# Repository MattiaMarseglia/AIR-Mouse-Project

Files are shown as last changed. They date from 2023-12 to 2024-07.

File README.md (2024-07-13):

# Air Mouse System Fingers Based (STM32CubeIDE)
<div align='center'>
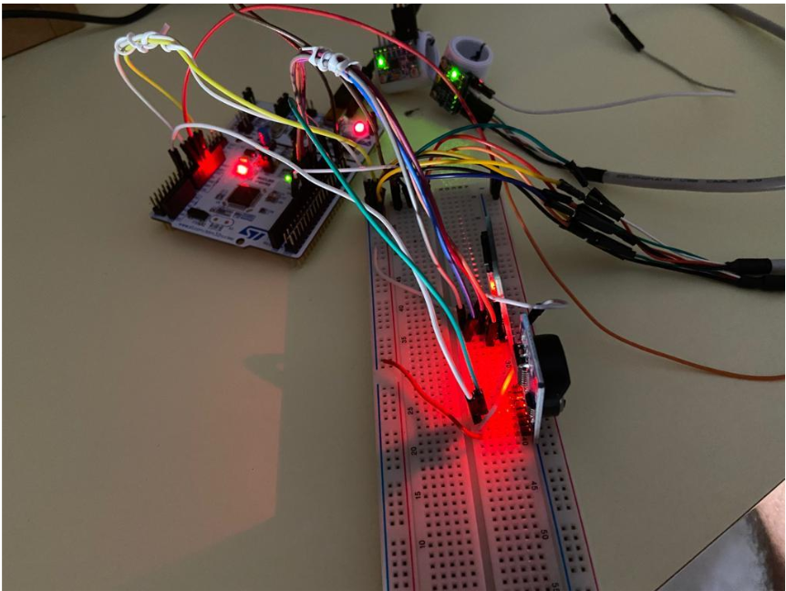
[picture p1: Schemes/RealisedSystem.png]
  
</div>

## Overview
The **Air Mouse System Fingers Based** project involves the creation of a gesture-controlled mouse using a combination of accelerometers, gyroscopes, a real-time clock (RTC), and an SD card module. The goal is to allow users to control their computer's mouse cursor by moving their fingers in the air, creating patterns and gestures for various actions, like movement, click, double-click etc.

## Developed System 
For the realisation of the Air Mouse, it was necessary to: 
- create a system capable of interpreting the basic commands of a common mouse, like **single click**, **double click**, **zoom in**, **zoom out**, **ALT-TAB**, with a specific fingers movement, acquiring data from accelerometers;
- create a system capable of **recording each event** (e.g. movement) by acquiring the timestamp from the RTC and writing it to the SD card witha representation such as: from:(x,y,z); to:(x,y ,z); accel: (x,y,z); gyro: (x,y,z) etc.;
- define different tasks for different activities(log, sensors' input, etc.), employing FreeRTOS, eventually with time constraints;
- design a suitable communication protocol from the STM32-Air mouse to the PC;
- define a calibration procedure.
- create a system that is correct, verifiable, modular and easily maintainable but also ready and fluid in responding to finger movements.

### Hardware
#### Hardware Components
- STM32F401RET6 board from the Nucleo series;
- 2 Modulo GY-521, build to manage MPU-6050, which combines an 3-axis accelerometer, a 3-axis gyroscope, a temperature sensor, an internal clock oscillation and a digital motion processor (DMP);
- Real-Time Clock (RTC) DS3231;
- Micro SD card adapter module;
#### Hardware Architecture
As can be seen in the high-level hardware architecture, it was necessary to interface the board and thus the processor with external peripherals. The board in turn is connected to the PC to which, as soon as the code has been loaded, it will transmit the data obtained, which will be reflected in mouse movements.  This data will be obtained by processing the values measured by the accelerometers along the three axes. The other two sensors, namely the RTC and the SD are functional to the development of a log file, saved on an SD card contained within the SD module. Specifically, the Real Time Clock is required to obtain a timestamp, so that all recorded movements and their associated values can be documented on the file, placing them temporally.
<div align='center'>
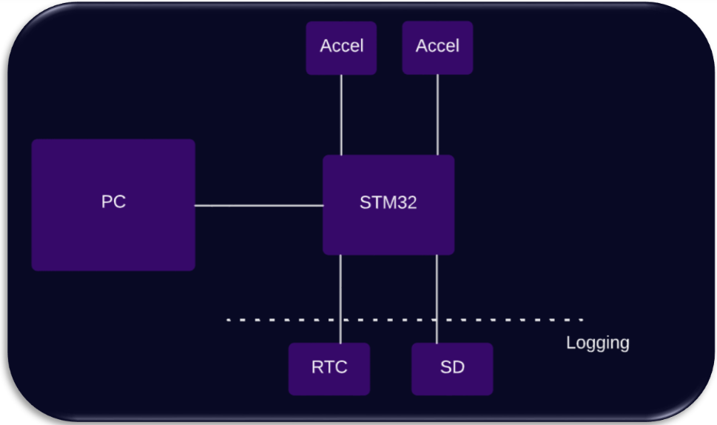
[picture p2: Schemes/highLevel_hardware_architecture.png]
High Level Hardware Architecture
  
</div>

As can be seen in the low-level hardare architecture, it was necessary to make use of a breadbord. 
<div align='center'>
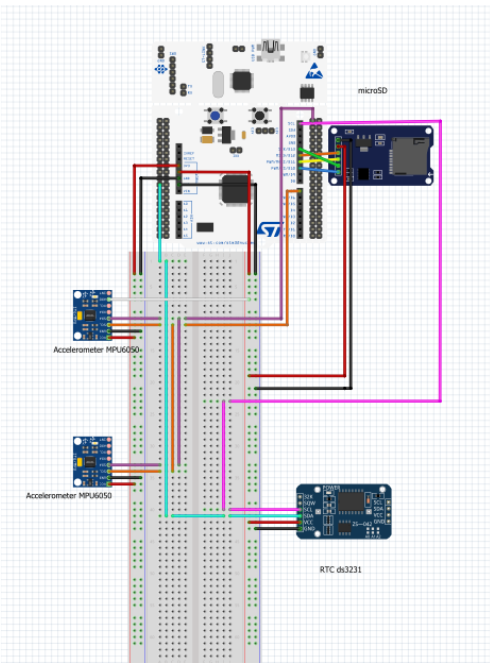
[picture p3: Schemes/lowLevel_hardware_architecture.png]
Low Level Hardware Architecture
  
</div>

For more details on the description of the connections made, please refer to the [report](ProgettoFinale_SE.pdf).

### Communication interface
Both the Real Time Clock and the two Accelerometers require I2C channels for communication with the board. So it was necessary to realise a protocol scheme that allows data acquisition from all sensors without creating overlaps. To this end, the board's availability of more than one I2C channel was exploited, as well as the possibility associated with the accelerometers alone, to be able to set up a register shift through which the
master can communicate with them. So that there was no overlap between the values communicated by the two different accelerometers. The microSD reader, on the other hand, uses an SPI connection. The communication with the PC is established through USART/UART, using a USB connection.
For more details about these comunication protocols, please refer to the [report](ProgettoFinale_SE.pdf).

### Software
#### Software Components
- STM32CubeIDE, an all-in-one multi-OS development tool, part of the STM32Cube software ecosystem;
- FreeRTOS, a space-saving, portable and open source real-time operating system (RTOS) for microcontrollers.
- PyAutoGUI, a Python GUI automation module cross-platform for humans, used to control at the code level the mouse and keyboard, and very useful to translate accelerometer values into mouse movements.
- PySerial, a module encapsulating the access for the serial port, that is useful to realise communication with the STM32 board so that motion commands can be acquired through the UART communication protocol.

#### Software Architecture
The software architecture was realised by identifying three tasks of freeRTOS with the same priority and different functionalities. The implemented tasks were identified from the
main functionalities that were to be offered by the system. So, a first *LectureTask* was implemented for the acquisition of data from accelerometers, which has a stack size of 128 words and whose priority is RealTime. The second task *AnalysisTask*, with a stack size of 128 words and a RealTime priority, deputed to recognize, depending on the values obtained from the accelerometers, which movement has to be made and send that analysis to the UART so that it can then communicate with the python modules to execute the user's commands. The third *LogTask* task, on the other hand, is responsible for writing the log file to the SD card and has a stack larger stack size of 2048 words and a RealTime priority. So, the read task is a periodic task. The activity of the other two tasks, on the other hand, depends on the presence of values to be parsed within the queues. Specifically, the queues created
were two: the first *LtoAqueue* serves as the
connection between the read task and the analysis task, the second *AtoLogqueue* serves as the connection between the analysis task and the log task. 

The control software was realised in C, for more details on the implemented modules, please refer to the [report](ProgettoFinale_SE.pdf).

## Repository Structure
- `ConfigTrio_RTC_1A2ASisEmbFinalProject/`: contains all the code developed for the system;
- `ProvaMouse`: contains a python script to test the system;
- `FinalProjectSistEmbBreadboard.fzz` and `SchemaConnessioni.fzz`: are the projects of the connection schemes;
- `ProgettoFinale_SE.pdf`: is the final report containing descriptive diagrams of the realised architecture, the motivations underlying certain design choices, details of the developed modules, hardare and software components descriptions and images depicting how to use the system;

## DEMO 
[Here](https://youtu.be/58L7y2n-bBM) it is possible to see a demo video of the developed system and all the implemented features.

## Feedback
For any feedback, questions or inquiries, please contact the project maintainers listed in the Contributors section.

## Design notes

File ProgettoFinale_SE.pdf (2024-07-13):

# Air Mouse – Fingers

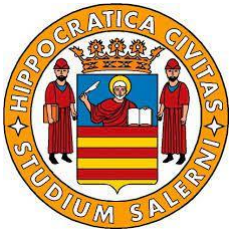
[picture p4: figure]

# AIR MOUSE – FINGERS

# Sistemi Embedded

# Final Project

Based on STM32F401RET6

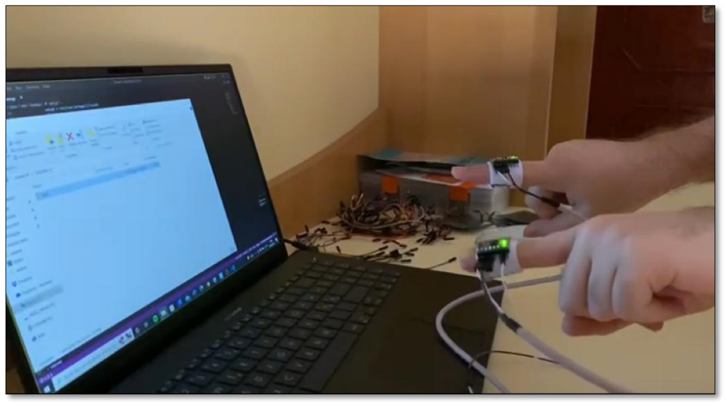
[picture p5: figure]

GRUPPO | | C.d.L. Ingegneria Informatica Magistrale
Vito Turi | 0622701795 | A.A. 2021/2022
Ferdinando Sica | 0622701794
Camilla Spingola | 0622701698
Mattia Marseglia | 0622701697

## Sommario

PySerial 30

## 1 Introduzione

## 1.1 Scopo del documento

Questo documento si pone l’obiettivo di descrivere lo sviluppo del progetto finale del corso di Sistemi Embedded, che ha

riguardato la realizzazione di un Air Mouse, utilizzabile tramite le dita di una mano.

Il presente documento viene allegato al progetto finale come documentazione ufficiale, al fine di offrire una descrizione

completa delle specifiche funzionali del sistema, nonché della componentistica hardware utilizzata e dell’architettura

software implementata.

## 1.2 Scopo del progetto

Il progetto finale del corso di Sistemi Embedded ha riguardato la realizzazione di un dispositivo Air Mouse controllabile

con le mani, in grado di interpretare la maggior parte dei comandi eseguibili attraverso un comune mouse (movimento,

click, double click etc.…), che analizzeremo successivamente.

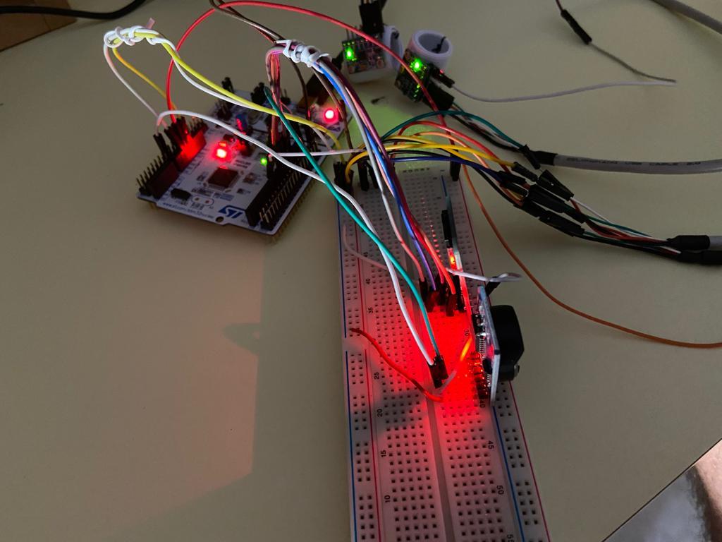
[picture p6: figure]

## 2 Hardware utilizzato

## 2.1 Descrizione della board

Per la progettazione e la realizzazione dell’Air Mouse, è stata utilizzata la board STM32F401RET6 della serie Nucleo. I

dispositivi STM32F401xD/xE sono basati sul core RISC a 32 bit ARMCortex-M4 ad alte prestazioni che opera a una

frequenza fino a 84 MHz. Il suo core Cortex-M4 è dotato di un'unità a virgola mobile (FPU) a precisione singola che

supporta tutte le istruzioni di processing dei dati e tutti i tipi di dato a singola precisione ARM. Implementa inoltre un set

completo di istruzioni DSP e un'unità di protezione della memoria (MPU) che migliora la sicurezza delle applicazioni.

STM32F401xD/xE incorpora memorie embedded ad alta velocità (512 Kbyte di memoria Flash, 96 Kbyte di SRAM) e una

vasta gamma di I/O e periferiche avanzate collegate a due bus APB, a due bus AHB e a una matrice bus multi-AHB a 32

bit.

Tutti i dispositivi offrono un ADC a 12 bit, un RTC a bassa potenza, 6 timer a 16 bit per uso generico, tra cui un timer

PWM per il controllo del motore, due timer a 32 bit per uso generale. Sono inoltre dotati di interfacce di comunicazione

standard e avanzate.

### Caratteristiche

- Core: CPU Arm32-bit Cortex-M4 con FPU, acceleratore adattivo in tempo reale (ART Accelerator™) che consente

l'esecuzione dello stato di attesa 0 dalla memoria Flash, frequenza fino a 84 MHz, unità di protezione della memoria, 105

DMIPS / 1,25 DMIPS / MHz (Dhrystone 2.1) e istruzioni DSP

- Memoria
- fino a 512 Kbyte di memoria Flash
- fino a 96 Kbyte di SRAM
- Gestione del clock, del reset e dell’alimentazione
- Alimentazione dell'applicazione e I/O da 1,7 V a 3,6 V
- POR, PDR, PVD e BOR
- Oscillatore a cristallo da 4 a 26 MHz
- RC interno a 16 MHz
- Oscillatore 32 kHz per RTC con calibrazione
- RC interno a 32 kHz con calibrazione
- Consumo energetico
- Funzionamento: 146 μA/MHz (periferica spenta)
- Stop (Flash in modalità Stop, fast wake-up time): 42 μA Typ @ 25C; 65 μA max @25 °C
- Stop (Flash in modalità Deep power down, fast wake-up time): fino a 10 μA @ 25 °C; 30 μA max @25 °C
- Standby: 2,4 μA @ 25 °C / 1,7 V senza RTC; 12 μA @85 °C @1.7 V
- alimentazione per RTC: 1 μA @25 °C

- Convertitore A/D 1×12 bit, 2.4 MSPS: fino a 16 canali
- DMA per uso generico: controller DMA a 16 flussi con FIFO e supporto burst
- Fino a 11 timer: fino a sei timer a 16 bit, due timer a 32 bit fino a 84 MHz, ciascuno con un massimo di quattro IC/OC/PWM o

un contatore di impulsi e un ingresso encoder in quadratura (incrementale), due timer watchdog (indipendenti e finestrato) e un

timer SysTick

- Modalità di debug
- Interfacce SWD (Serial Wire Debug) e JTAG
- Cortex-M4 Embedded Trace Macrocell
- Fino a 81 porte I/O con capacità di interruzione
- Fino a 78 I/O veloci fino a 42 MHz
- Tutte le porte I/O sono tolleranti a 5 V
- Fino a 12 interfacce di comunicazione
- Fino a 3 Interfacce 12C (SMBus/PMBus)
- Fino a 3 USART (2 x 10,5 Mbit/s, 1 x 5,25 Mbit/s), interfaccia ISO 7816, LIN, IrDA, controllo modem)
- Fino a 4 SPI (fino a 42Mbit/s a fCPU= 84 MHz), SPI2 e SPI3 con muxed full-duplex I2S per ottenere la precisione

della classe audio attraverso l’audio interno PLL o il clock esterno

- Interfaccia SDIO
- Connettività avanzata: USB 2.0 full speed device/ host / controller OTG con PHY su chip
- Unità di calcolo CRC
- ID univoco a 96 bit
- RTC: precisione al di sotto del secondo, calendario hardware

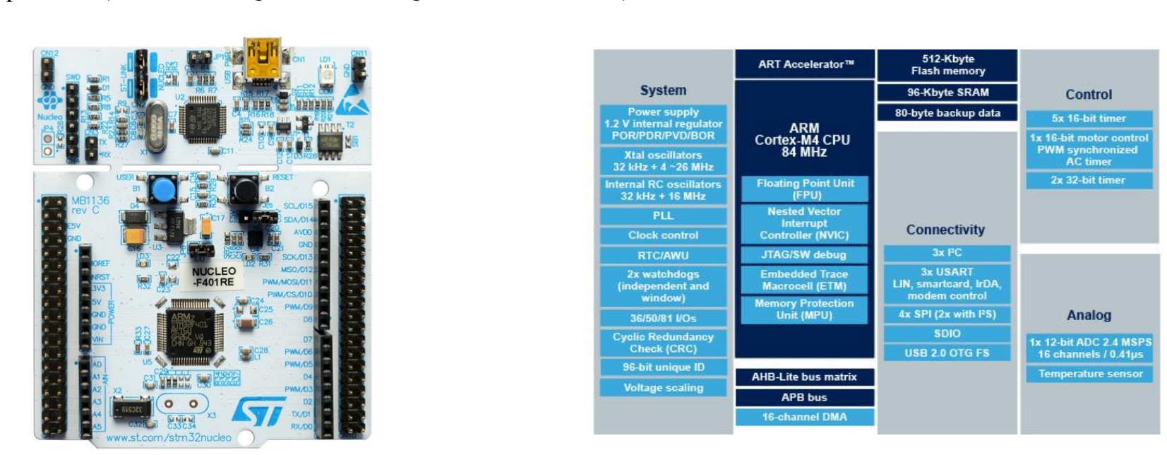
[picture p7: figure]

- Tutti i pacchetti (WLCSP49, LQFP64/100, UFQFPN48, UFBGA100) sono ECOPACK2

## 2.2 Descrizione dei sensori

### Modulo GY-521 MPU-6050

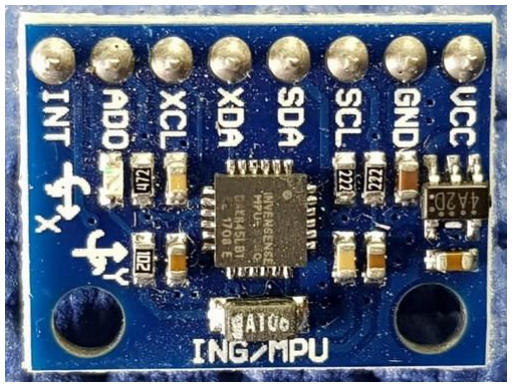
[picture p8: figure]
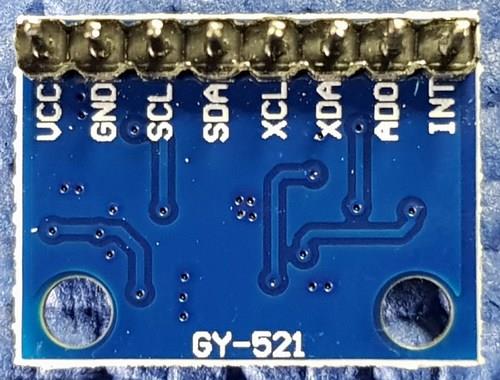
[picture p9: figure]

Il modulo GY-521 (https://win.adrirobot.it/sensori/MPU-6050/sensore_MPU-6050.htm) è costruito per gestire il sensore MPU-6050 che combina al suo interno più dispositivi, tra i quali

notiamo:

- un accelerometro a 3 assi
- un giroscopio a 3 assi
- un sensore di temperatura
- un oscillare di clock interno
- un processore di movimento digitale

Il modulo è di piccole dimensioni: 21.2 x 16.4 x 3.3 mm, è dotato in hardware di conversione analogico-digitale per

ciascun canale, e consente l’acquisizione dai canali x, y, z. L'uscita può essere interfacciata con il bus I2C.

Accelerometro a 3 assi

L'accelerometro a 3 assi interno all'MPU-6050 è in grado di rilevare l'angolo di inclinazione o l'inclinazione lungo gli assi

x, y, z utilizzando una tecnologia del sistema elettromeccanico (Micro Electro-Mechanical Systems MEMS). (https://it.wikipedia.org/wiki/MEMS)

L'accelerazione lungo gli assi è ricavata dalla massa in movimento c, rilevata con la tecnologia del sistema

elettromeccanico (MEMS). Per la digitalizzazione dei valori viene utilizzato un ADC a 16 bit. Gli intervalli di uscita a

fondo scala possibili sono: +/- 2g, +/- 4g, +/- 8g, +/- 16g.

In posizione normale, cioè quando il dispositivo è posizionato su una superficie piana, i valori sono 0 g sull'asse x, 0 g

sull'asse y e +1 sull'asse z.

Giroscopio a 3 assi

L'MPU-6050 è costituito da un giroscopio a 3 assi in grado di rilevare la velocità di rotazione lungo l'asse x, y, z con la

tecnologia del sistema micro-elettromeccanico (MEMS). Quando il sensore viene ruotato su qualsiasi asse, viene prodotta

una vibrazione, grazie all'effetto Coriolis (https://it.wikipedia.org/wiki/Forza_di_Coriolis) viene rilevata dal MEMS. L'ADC a 16 bit viene utilizzato per digitalizzare la

tensione per campionare ciascun asse. Gli intervalli di uscita a fondo scala sono: +/- 250, +/- 500, +/- 1000, +/- 2000. La

velocità angolare viene misurata lungo ciascun asse in gradi al secondo.

Oscillatore di clock interno

L'MPU ha uno schema di temporizzazione flessibile, che consente di utilizzare una varietà di sorgenti di clock interne o

esterne per i circuiti sincroni interni. Questa circuiteria sincrona include il segnale di condizionamento e gli ADC, il DMP e

i vari circuiti e registri di controllo. Un PLL su chip offre flessibilità negli input consentiti per generare il clock.

Le fonti interne consentite per generare il clock interno sono:

- Un oscillatore di rilassamento interno
- Qualunque giroscopio X, Y o Z (oscillatori MEMS con una variazione di ± 1% rispetto alla temperatura)

Digital motion processor (DMP)

Il processore di movimento digitale incorporato viene utilizzato per eseguire calcoli sui dati del sensore. I valori possono

essere letti dai registri dmp. I valori grezzi possono essere letti direttamente dall'accelerometro e dai registri del giroscopio.

Il chip MPU-6050 include anche un buffer FIFO da 1024 byte dove i dati possono essere posizionati e letti. L'MPU-6050

funge sempre da slave quando è connesso alla scheda con i pin SDA e SCL collegati al bus I2C. Ma ha anche il proprio

controller I2C ausiliario che gli consente di agire come un master su un altro dispositivo (come per esempio un

magnetometro). Il DMP integrato può essere programmato con il firmware per eseguire calcoli complessi con i valori del

sensore.

L'AD0 seleziona tra gli indirizzi I2C 0x68 e 0x69 consentendo a 2 di questi sensori di essere connessi nello stesso progetto

agli stessi pin senza creare sovrapposizione tra i dati. La maggior parte delle schede come la GY-521 ha una resistenza pull

down o pull up per mantenere il valore predefinito, nel nostro caso al valore 0x68.

Caratteristica sensore

Alimentazione a 5Vcc

Fondo scala giroscopio selezionabile tra ± 250, ± 500, ± 1000, e ± 2000°/sec

Fondo scala accelerometro selezionabile tra ± 2g, ± 4g, 8g ± e ± 16g

Interfaccia I2C

Assorbimento inferiore a 10mA durante la misura

Descrizione dei Pin

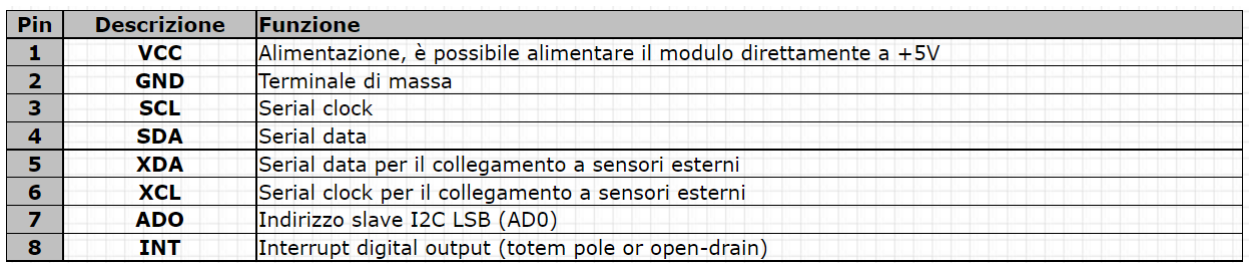
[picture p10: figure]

### Real Time Clock ds3231

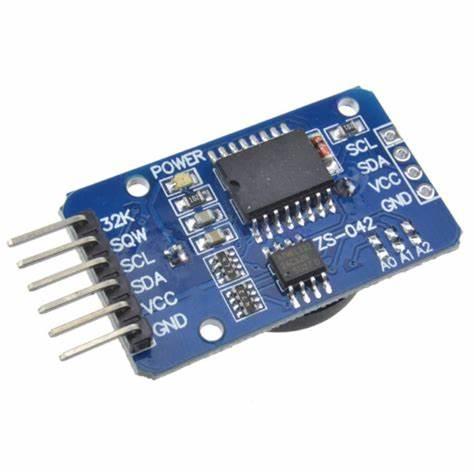
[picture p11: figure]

Il DS3231 è un Real Time Clock estremamente preciso e a basso consumo, con un TCXO (temperature compensated

crystal oscillator) integrato. Il dispositivo incorpora un ingresso batteria e mantiene un cronometraggio accurato anche

quando l'alimentazione principale al dispositivo viene interrotta. L'RTC mantiene secondi, minuti, ore, giorni, mese e anno.

La data relativa alla fine del mese viene regolata automaticamente per i mesi con meno di 31 giorni, comprese le correzioni

per l'anno bisestile. L'orologio funziona nel formato 24 ore o 12 ore con un indicatore AM/PM. Sono forniti due allarmi

programmabili e un'uscita ad onda quadra programmabile. Indirizzi e dati vengono trasferiti in serie attraverso un bus

bidirezionale I2C.

Un riferimento di tensione di precisione con compensazione della temperatura e un circuito comparatore controlla lo stato

di VCC per individuare interruzioni di corrente, per fornire un’uscita di ripristino e per passare automaticamente

all'alimentazione di riserva quando necessario.

Features

- Highly Accurate RTC Completely Manages All
- Timekeeping Functions
- Real-Time Clock Counts Seconds, Minutes, Hours,
- Date of the Month, Month, Day of the Week, and Year, with Leap-Year Compensation Valid Up to 2100
- Accuracy ±2ppm from 0°C to +40°C
- Accuracy ±3.5ppm from -40°C to +85°C
- Digital Temp Sensor Output: ±3°C Accuracy
- Register for Aging Trim
- RST Output/Pushbutton Reset Debounce Input
- Two Time-of-Day Alarms
- Programmable Square-Wave Output Signal
- Simple Serial Interface Connects to Most Microcontrollers
- Fast (400kHz) I2C Interface
- Battery-Backup Input for Continuous Timekeeping
- Low Power Operation Extends Battery-Backup Run Time
- 3.3V Operation
- Operating Temperature Ranges: Commercial (0°C to +70°C) and Industrial (-40°C to +85°C)

Operating circuit

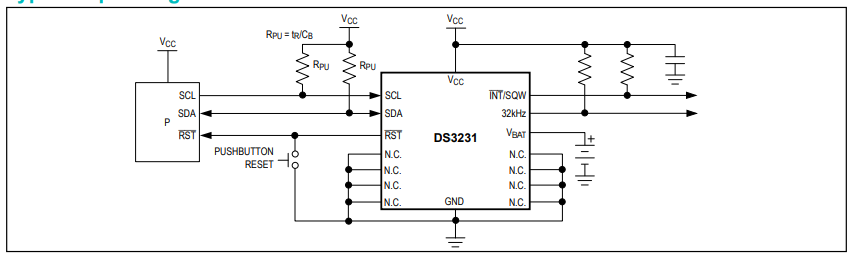
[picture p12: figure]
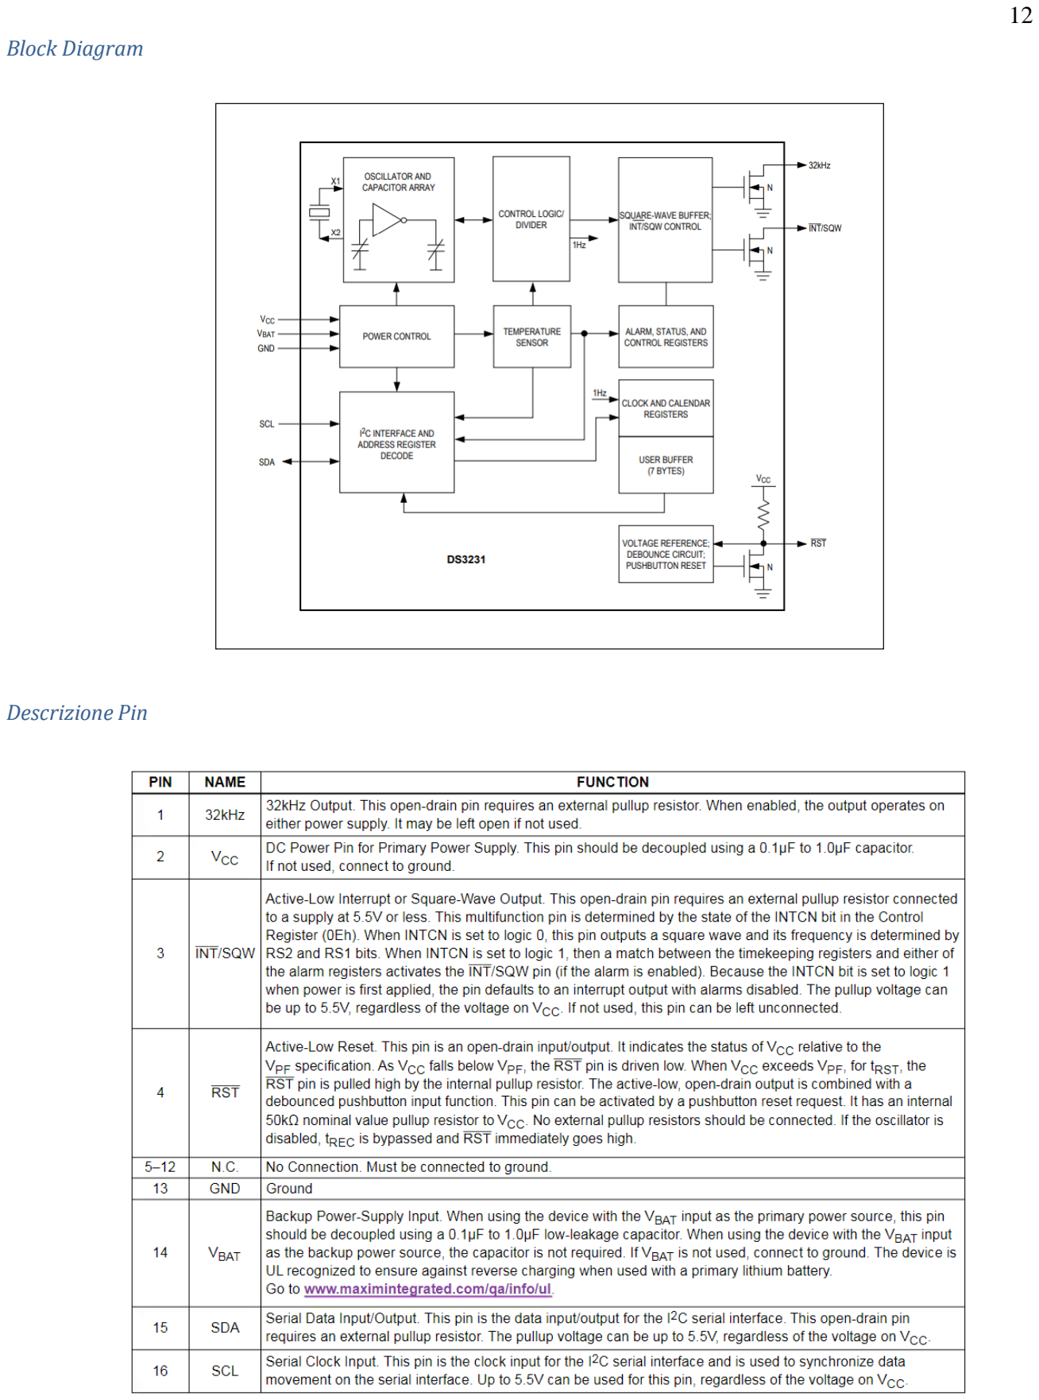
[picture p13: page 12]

Block Diagram

Descrizione Pin

### Modulo adattatore per scheda Micro SD

Le schede SD o Micro SD sono ampiamente utilizzate in varie applicazioni, come la registrazione dei dati, la

visualizzazione dei dati e molte altre. I moduli Micro SD Card Adapter rendono possibile accedere a queste schede SD con

facilità. Il modulo Micro SD Card Adapter è dotato di un'interfaccia SPI e di un regolatore di tensione da 3,3 V integrato

per fornire una corretta alimentazione alla scheda SD.

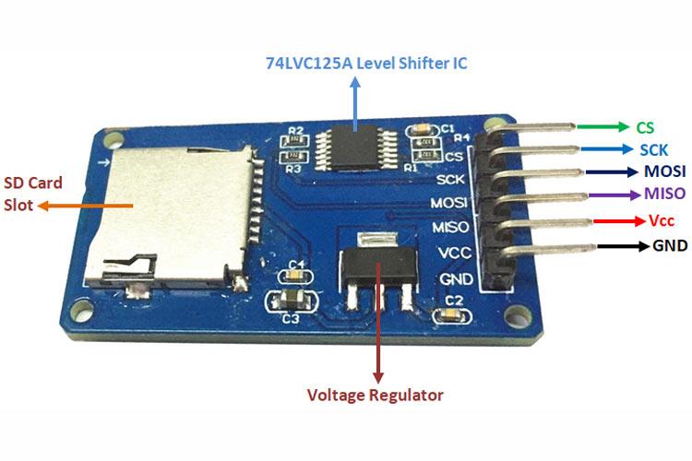
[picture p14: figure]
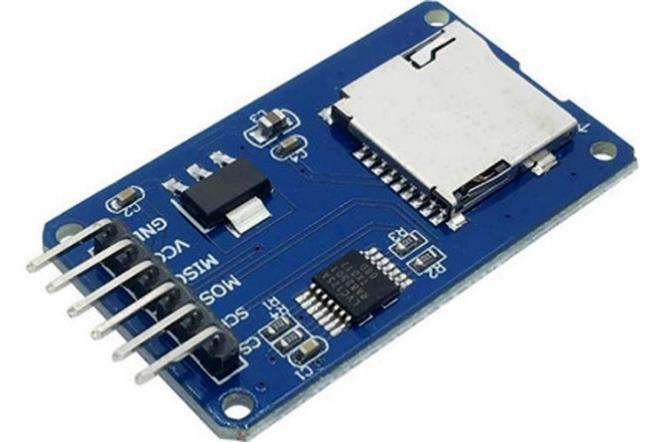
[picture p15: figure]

Caratteristiche e specifiche del modulo adattatore per scheda Micro SD

Questa sezione menziona alcune delle caratteristiche e delle specifiche del modulo adattatore per schede Micro

SD.

- Tensione di funzionamento: 4,5 V - 5,5 V CC
- Requisito attuale: 0,2-200 mA
- Regolatore di tensione di bordo da 3,3 V
- Supporta il file system FAT
- Supporta micro SD fino a 2GB
- Supporta Micro SDHC fino a 32GB

Configurazione Pin del modulo adattatore per scheda Micro SD

Il modulo contiene 6 pin per l'alimentazione e la comunicazione con il controllore. La tabella seguente descrive il tipo di

pin e il ruolo di ciascun di ciascuno di essi sul modulo.

Collegamento del modulo adattatore per scheda Micro SD a un MCU/MPU

Un modulo adattatore micro-SD card può essere facilmente collegato a un MCU/MPU. Poiché il modulo

comunica tramite il protocollo SPI, è necessario collegare MISO, MOSI, SCK e CS del modulo agli MCU.

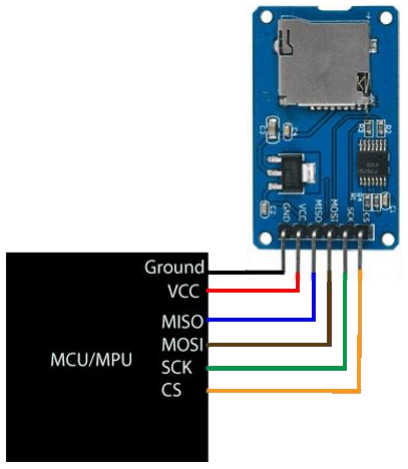
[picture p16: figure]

## 3 Software utilizzato

## 3.1 StmCubeIDE

STM32CubeIDE è uno strumento di sviluppo multi-OS all-in-one, che fa parte dell'ecosistema software STM32Cube.

STM32CubeIDE è una piattaforma di sviluppo C/C++

avanzata con funzionalità di configurazione periferica,

generazione di codice, compilazione di codice e debug per

microcontrollori e microprocessori STM32. Si basa sul

framework Eclipse / CDT™ e sulla toolchain GCC per lo

sviluppo e GDB per il debug. Permette l'integrazione delle

centinaia di plugin esistenti che completano le funzionalità

dell'IDE Eclipse.

STM32CubeIDE integra le funzionalità di configurazione e creazione di progetti STM32 di STM32CubeMX per offrire

un'esperienza utente all-in-one e risparmiare tempo di installazione e sviluppo. Dopo la selezione di un MCU o MPU

STM32 vuoto, o di un microcontrollore o microprocessore preconfigurato dalla selezione di una scheda o dalla selezione di

un esempio, viene creato il progetto e generato il codice di inizializzazione. In qualsiasi momento durante lo sviluppo,

l'utente può tornare all'inizializzazione e alla configurazione delle periferiche o del middleware e rigenerare il codice di

inizializzazione senza alcun impatto sul codice utente.

STM32CubeIDE include analizzatori di compilazione e stack che forniscono all'utente informazioni utili sullo stato del

progetto e sui requisiti di memoria.

STM32CubeIDE include anche funzionalità di debug standard e avanzate, tra cui visualizzazioni di registri core CPU,

memorie e registri periferici, nonché clock variabile in live, interfaccia Serial Wire Viewer o analizzatore di guasti.

### Caratteristiche

- Integrazione dei servizi da STM32CubeMX: STM32 microcontroller, microprocessore, piattaforma di sviluppo ed esempio di

selezione del progetto Pinout, clock, periferiche e middleware. Creazione del progetto e generazione del codice di

inizializzazione. Software e middleware completati con pacchetti di espansione STM32Cube avanzati.

- Basato su Eclipse/CDT™, con supporto per componenti aggiuntivi Eclipse, toolchain GNU C/C++ for Arm e debugger GDB
- Serie STM32MP1: Supporto per progetti OpenST Linux.
- Altre funzionalità di debug avanzate, tra cui: analisi dei core della CPU, analisi delle periferiche, visualizzazione della

memoria (variabili), analisi del sistema e tracciamento in tempo reale (SWV), strumento di analisi dei guasti della CPU e

supporto di debug compatibile con RTOS, incluso Azure.

- Supporto per sonde di debug ST-LINK (STMicroelectronics) e J-Link (SEGGER)
- Progetto di importazione da Atollic True STUDIO e AC6 System Workbench per STM32 (SW4STM32)
- Supporto multi-OS: Windows, Linux e macOS, solo versioni a 64 bit

## 3.2 FreeRTOS

FreeRTOS è un sistema operativo in tempo reale (https://it.frwiki.wiki/wiki/Syst%C3%A8me_d%27exploitation_temps_r%C3%A9el) ( RTOS (https://it.frwiki.wiki/wiki/RTOS) ) a ingombro (https://it.frwiki.wiki/wiki/Empreinte_%C3%A9cologique) ridotto, portatile (https://it.frwiki.wiki/wiki/Portabilit%C3%A9_(informatique)) , preventivo (https://it.frwiki.wiki/wiki/Multit%C3%A2che_pr%C3%A9emptif) e open source (https://it.frwiki.wiki/wiki/Open_source) per microcontrollori (https://it.frwiki.wiki/wiki/Microcontr%C3%B4leur) . È stato portato su oltre 40 architetture diverse. Creato nel 2003 da Richard Barry e dal Team FreeRTOS,

è oggi tra i più utilizzati nel mercato dei sistemi operativi in tempo reale.

Il numero di attività in esecuzione contemporaneamente e la loro priorità sono limitate solo dall'hardware. La

pianificazione è un sistema di accodamento basato su Semafori (https://it.frwiki.wiki/wiki/Exclusion_mutuelle) e Mutex (https://it.frwiki.wiki/wiki/Exclusion_mutuelle) . Si basa sul modello Round-Robin (https://it.frwiki.wiki/wiki/Round-robin_(informatique)) con gestione

delle priorità. Progettato per essere molto compatto, consiste solo di pochi file in linguaggio C e non implementa alcun

driver (https://it.frwiki.wiki/wiki/Pilote_informatique) hardware.

I campi di applicazione sono piuttosto ampi, in quanto i principali vantaggi di FreeRTOS sono l'esecuzione in tempo reale,

il codice open source e le dimensioni molto ridotte. Viene quindi utilizzato principalmente per sistemi embedded (https://it.frwiki.wiki/wiki/Syst%C3%A8me_embarqu%C3%A9) che hanno

vincoli di spazio per il codice, ma anche per sistemi di elaborazione video e applicazioni di rete che hanno vincoli di tempo

reale.

Il suo design è volutamente minimalista per poter essere installato su piccoli impianti. L'immagine binaria (https://it.frwiki.wiki/wiki/Image_binaire) del core (https://it.frwiki.wiki/wiki/Noyau_de_syst%C3%A8me_d%27exploitation) pesa tra

4 KB (https://it.frwiki.wiki/wiki/Byte) e 9 KB (https://it.frwiki.wiki/wiki/Byte) (4,3 KB compilati su ARM7). Il kit minimale ha solo poche funzioni per gestire le attività e la memoria.

Inoltre, sono implementate code (https://it.frwiki.wiki/wiki/File_d%27attente_de_message) , semafori (https://it.frwiki.wiki/wiki/S%C3%A9maphore_(informatique)) e mutex. (https://it.frwiki.wiki/wiki/Exclusion_mutuelle)

Il kernel di versione 7.3.0 è composto di soli cinque file codificati in linguaggio C. (https://it.frwiki.wiki/wiki/C_(langage)) Le sezioni in Assembler consentono di

garantire la compatibilità di FreeRTOS con le diverse architetture hardware.

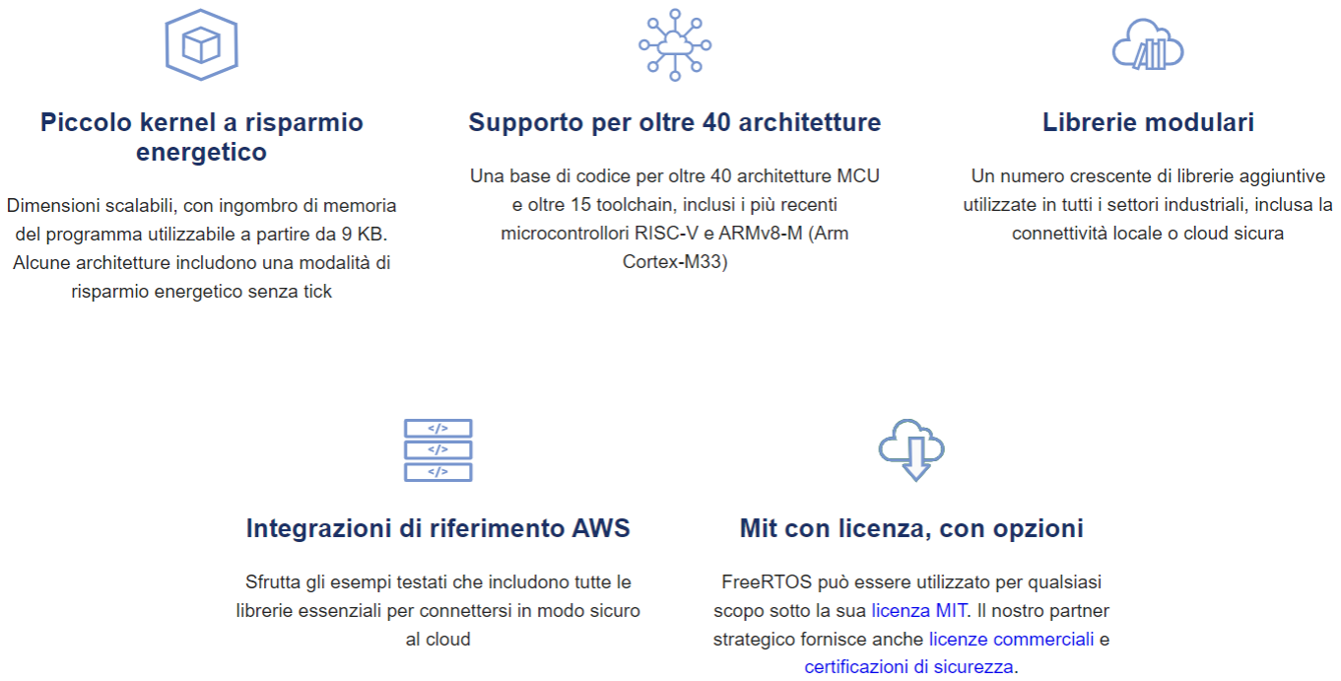
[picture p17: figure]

Essendo un sistema operativo puramente orientato al tempo reale fornito senza un'applicazione, spesso funge da base per lo

sviluppo di API specifiche e/o proprietarie. Viene quindi utilizzato in un'ampia varietà di campi in cui il vincolo del tempo

reale è forte, come ad esempio: dispositivi di sorveglianza medica, strumenti di controllo sismico e ambientale o persino il

controllo di dispositivi industriali e robot. Le sue funzionalità di gestione delle attività garantiscono l'integrità dei dati

raccolti in tempo reale utilizzando i più alti livelli di priorità.

## 4 Specifiche del sistema

## 4.1 Specifiche funzionali

L’Air Mouse è grado di interpretare i comandi basilari di un comune mouse. Più nello specifico, il progetto richiedeva di

implementare varie funzionalità:

- riprodurre un click singolo attraverso un determinato movimento delle dita (acquisendo i dati dagli accelerometri).
- riprodurre un doppio click singolo attraverso un determinato movimento delle dita (acquisendo i dati dagli accelerometri).
- riprodurre i movimenti del mouse attraverso l’acquisizione dei dati dagli accelerometri.
- riprodurre uno zoom in attraverso un determinato movimento delle dita (acquisendo i dati dagli accelerometri).
- riprodurre uno zoom out attraverso un determinato movimento delle dita (acquisendo i dati dagli accelerometri).
- riprodurre un ALT-TAB attraverso un determinato movimento delle dita (acquisendo i dati dagli accelerometri).
- Registrare ogni evento (es.: movimenti) tramite la l’acquisizione del timestamp dall’ RTC e la sua scrittura sulla SD card con

una rappresentazione del tipo: from:(x,y,z); to:(x,y ,z); accel: (x,y,z); giroscopio: (x,y,z) ecc.

- Utilizzare task diversi per attività diverse (log, input dei sensori, ecc.), programmato in FreeRTOS (eventualmente con vincoli

in tempo reale).

- progettare un protocollo di comunicazione adeguato dal mouse STM32-Air al PC.
- Calibrare l'Air Mouse.

## 4.2 Specifiche non funzionali

Il software realizzato deve essere in grado di ottenere un funzionamento del mouse tale da:

- essere Corretto e Verificabile, rispetto ai requisiti funzionali elencati precedentemente.
- essere Pronto e Fluido nel rispondere ai movimenti delle dita.

Anche se per questo progetto non sono requisiti obbligatori è comunque buona norma cercare di realizzare un software

modulare e facilmente manutenibile.

## 5 Progettazione

## 5.1 Schema elettrico

Di seguito vengono riportati degli schemi di interesse per il progetto realizzato. Viene dapprima riportato uno schema

semplificativo delle connessioni effettuate, e successivamente viene riportato lo schema dei collegamenti elettrici realizzati.

### Visione High Level

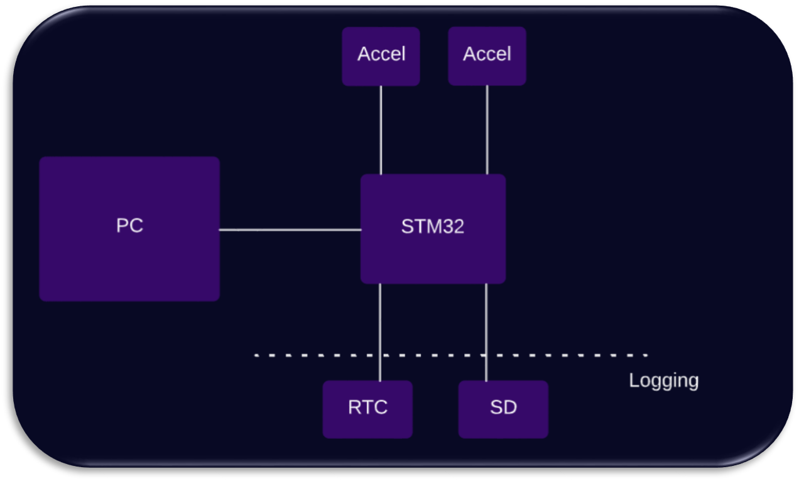
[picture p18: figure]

Ciò che si vede nell’immagine sopra riportata è una visione di alto livello dello schema hardware. Come già

precedentemente detto, i sensori utilizzati sono due accelerometri, un Real Time Clock e un Modulo SD. Dunque, dal punto

di vista hardware è stato necessario l’interfacciamento della scheda e quindi del processore con tali periferiche esterne. La

scheda a sua volta sarà connessa al PC al quale, non appena il codice sarà stato caricato, trasmetterà i dati ottenuti, che si

ripercuoteranno, tramite l’utilizzo di apposite librerie python, in movimenti del mouse. I due accelerometri

comunicheranno i valori rilevati, ovvero i valori di accelerazione misurati lungo i tre assi, i quali, a seguito di

un’elaborazione, saranno tradotti in movimenti del mouse. Gli altri due sensori, ovvero l’RTC e l’SD saranno invece

funzionali allo sviluppo di un file di log, salvato su una scheda SD contenuta all’interno del modulo SD. Nello specifico il

Real Time Clock sarà necessario per l’ottenimento di un timestamp, così che sul file si potranno documentare tutti i

movimenti registrati e i rispettivi valori associati, collocandoli temporalmente.

### Visione low Level

Quella sopra riportata è la visualizzazione basso livello dello schema hardware realizzato. A tale scopo è stato necessario

anche l’impiego di una breadboard. La descrizione delle connessioni per ciascun sensore è riportata di seguito, in forma testuale, all’interno della tabella dei pin. È però necessario porre attenzione su alcune connessioni. Sia il Real Time Clock

che i due Accelerometri necessitano di canali I2C per la comunicazione con la scheda. Dunque, in tale fase è stato

necessario realizzare uno schema di protocollo che consentisse l’acquisizione dei dati da tutti i sensori senza creare delle

sovrapposizioni. A tale scopo si è sfruttata la disponibilità della scheda di più di un canale I2C, oltre che la possibilità,

associata ai soli accelerometri, di poter mettere a punto uno shift del registro attraverso cui effettuare la comunicazione del

master con gli accelerometri. Dunque, un canale I2C, nello specifico I2C3, è stato destinato ai due accelerometri, mentre il

canale I2C1 è stato destinato al Real Time Clock. Questo spiega i collegamenti effettuati per tali sensori e anche il motivo per cui i due pin di SCL e di SDA degli accelerometri siano in serie. Affinché non ci fossero sovrapposizioni tra i valori

comunicati dai due diversi accelerometri, per uno dei due è stato effettuato lo shift del registro sopra descritto, in modo che

uno dei due fosse identificato dal registro 0x68 mentre l’altro dal registo 0x69. Per effettuare tale shift è stato necessario,

per l’accelerometro in questione, realizzare una connessione tra il pin AD0 e l’alimentazione a 5Volt, così come si vede in

figura. Il lettore della microSD invece sfrutta una connessione SPI tramite i collegamenti visibili in figura.

Sono state inoltre rispettate le specifiche dei datasheet di ciascun sensore relativamente alla tensione di alimentazione, per

cui alcuni risultano essere alimentati a 5Volt altri invece a 3,3Volt.

### Tabella dei Pin

Porta | Pin | Link
A | 5 | SCK Pin (Micro SD Card Module)
A | 6 | MISO Pin (Micro SD Card Module)
A | 7 | MOSI Pin (Micro SD Card Module)
A | 8 | SCL Pins (Two Accelerometers GY-521 MPU6050)
B | 6 | CS Pin (Micro SD Card Module)
B | 7 | SDA Pin (Real Time Clock DS3231)
B | 8 | SCL Pin (Real Time Clock DS3231)
C | 9 | SDA Pins (Two Accelerometers GY-521 MPU6050)

## 5.2 Architettura software

Di seguito è riportata una visione di alto livello della struttura software del sistema progettato. Nello specifico già ad alto

livello è possibile individuare dei task che successivamente sono stati tradotti in task veri e propri di freeRTOS. I task

individuabili sono tre. Il primo è sicuramente quello orientato al rilevamento dei dati dai sensori, in particolare al

rilevamento dei valori di accelerazione lungo gli assi registrati dai due accelerometri. Tali dati, presi in forma bruta,

vengono poi analizzati da un secondo task, il quale in tale fase di analisi si occupa di discriminare il tipo di variazione

registrata associandola all’eventuale comando corrispondente. A questo punto si diramano poi due task la cui evoluzione è

indipendente, a differenza di quelli appena descritti che invece prevedono una successione temporale. Tali due task sono

uno relativo alla trascrizione del file di log, per il quale è necessario memorizzare l’operazione svolta e il momento di

esecuzione di quest’ultima, e quello relativo all’esecuzione del comando richiesto dall’utente.

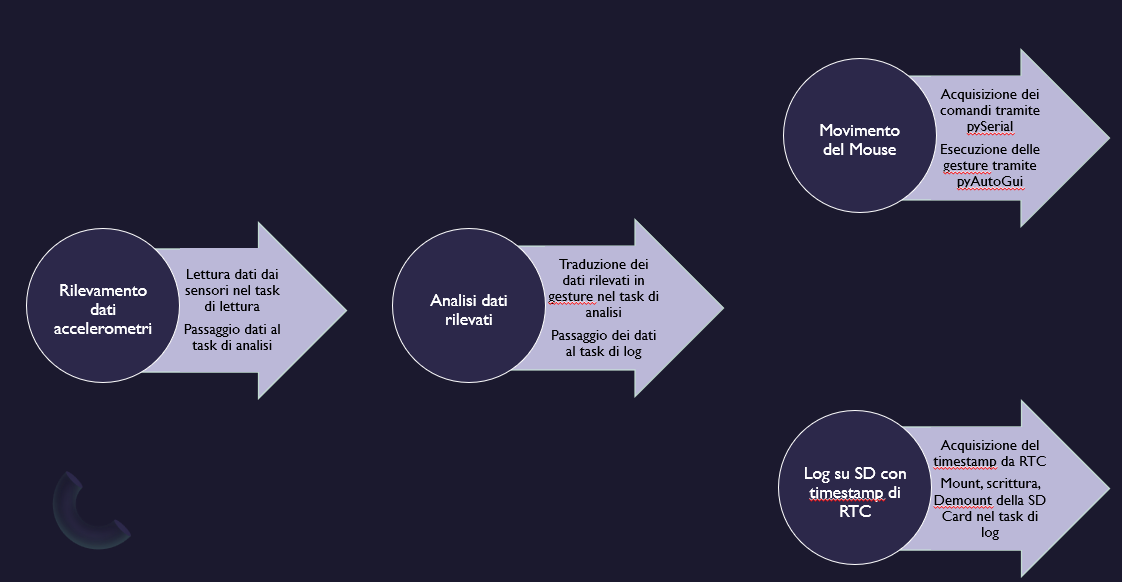
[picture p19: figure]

Per la compilazione del file di log si utilizza il modulo SD, attraverso cui si monta la micoSD, si aggiorna tale file già

esistente e si fa il demount successivo. Al fine di avere le diverse operazioni correttamente documentate temporalmente si

fa impiego del Real Time Clock, il quale mantiene il tempo dal primo settaggio.

Per far sì che il comando venga impartito si è fatto utilizzo di alcune librerie Python. Nello specifico il comando

individuato viene acquisito da tale modulo attraverso pySerial, che si appoggia dunque alla linea seriale. L’esecuzione vera

e propria del comando invece prevende l’impiego di pyAutoGui.

Il meccanismo di comunicazione tra i vari task, ad un livello poi più basso si tradurrà nell’impiego di queue per contenere i

dati scambiati tra i vari task.

### Moduli software

iIl Software di controllo è stato realizzato in linguaggio C. Non essendo stato utilizzato un linguaggio ad oggetti quello di

seguito riportato non figura come un diagramma UML delle classi vero e proprio, ma più che altro come una descrizione

visiva dei diversi moduli utilizzati all’ interno del software, delle relazioni che intercorrono tra questi e della descrizione di

eventuali strutture o tipi definite da noi stessi. Di seguito poi si procederà alla descrizione di ciascuno dei moduli.

Modulo SD card

- void Mount_SD (const TCHAR* path), Cancella il vecchio puntatore all'oggetto del file system, e ne crea e

registra uno nuovo per poter eseguire operazioni sulla memoria.

- void Unmount_SD (const TCHAR* path), riesegue un mount (il quale cancella il vecchio puntatore) però

impostando il nuovo puntatore a NULL, dunque senza crearne uno nuovo.

- FRESULT Scan_SD (char* pat), il quale scorre i file presenti nella microSD passandoli alla scheda la quale

tramite UART li trasferisce al computer

- | FRESULT Format_SD (void), | scorre tutti i file presenti nella microSD e ne esegue l’unlink, cancellandoli.
- FRESULT Write_File (char *name, char *data), cerca il file (con il nome come primo parametro) nella

microSD, successivamente lo crea se non è presente, lo apre in modalità scrittura e chiama l’effettiva f_write() la

quale scrive all’interno del file il contenuto del secondo parametro, infine chiude il file.

- FRESULT Read_File (char *name), cerca il file (con il nome come primo parametro) nella microSD, lo apre in

modalità lettura se è presente e chiama l’effettiva f_read() la quale legge il contenuto del file, infine chiude il file.

- FRESULT Create_File (char *name), il quale fa un check per verificare se esiste il file; quindi, prova a crearlo e
| successivamente lo chiude.
- FRESULT Update_File (char *name, char *data), esegue le operazioni fatte dalla funzione

Write_file(char*,char*), ma appendendo il secondo parametro invece di sovrascrivere il file.

- FRESULT Remove_File (char *name), cerca il file (con il nome come primo parametro) nella microSD,

successivamente lo rimuove se presente.

- FRESULT Create_Dir (char *name), prova a creare la cartella tramite la funzione f_mkdir(char *).
- void Check_SD_Space (void), controlla lo spazio libero nell microSD tramite funzione f_getfree(…)

successivamente ricava lo spazio finale e trasmette su UART i due valori.

Accelerometro

- void MPU6050_Init(I2C_HandleTypeDef *I2Chnd), Copia l'handle I2C CubeMX in una variabile locale.
- void I2C_Read(uint8_t ADDR, uint8_t *i2cBif, uint8_t NofData, int r), legge dei dati tramite I2C

(presenti nell’indirizzo passato come parametro) dagli accelerometri scrivendoli in un vettore passato come

parametro; questa funzione è utilizzata ad altre funzioni presenti all’interno della libreria (quelle di lettura

effettive).

- void I2C_Write8(uint8_t ADDR, uint8_t data), scrive i dati tramite I2C negli accelerometri passati come

parametro questa funzione è utile ad altre funzioni presenti all’interno della libreria (quelle di configurazione).

- void MPU6050_Config(MPU_ConfigTypeDef *config), configura gli accelerometri con tutti i settaggi passati

come parametro incluso scaling, filtri, etc….

- uint8_t MPU6050_Get_SMPRT_DIV(void), esegue la get del divisore di frequenza di campionamento.
- void MPU6050_Set_SMPRT_DIV(uint8_t SMPRTvalue), esegue il set del divisore di frequenza di

campionamento.

- uint8_t MPU6050_Get_FSYNC(void), esegue la get della sincronizzazione dei frame esterni.
- void MPU6050_Set_FSYNC(enum EXT_SYNC_SET_ENUM ext_Sync), esegue il set della sincronizzazione dei frame

esterni.

- void MPU6050_Get_Accel_RawData(RawData_Def *rawDef, int r), questa funzione legge lo stato degli

accelerometri dai registri e se può legge i valori di accelerometro lungo i vari assi immagazzinandoli in una struct.

- void MPU6050_Get_Accel_Scale(ScaledData_Def *scaledDef), la quale chiama

MPU6050_Get_Accel_RawData(RawData_Def *, int ) e riscala i valori adeguatamente ai parametri settati

salvandoli in una nuova struct (quella effettivamente usata dall’utente).

- void MPU6050_Get_Accel_Cali(ScaledData_Def *CaliDef), Ottiene i dati di

MPU6050_Get_Accel_Scale(ScaledData_Def *) ma li calibra.

- void MPU6050_Get_Gyro_RawData(RawData_Def *rawDef), questa funzione legge lo stato degli accelerometri

dai registri e se può legge i valori del giroscopio lungo i vari assi immagazzinandoli in una struct.

- void MPU6050_Get_Gyro_Scale(ScaledData_Def *scaledDef), la quale chiama

MPU6050_Get_Gyro_RawData(RawData_Def *, int ) e riscala i valori in maniera corretta salvandoli in unna

nuova struct (quella effettivamente usata dall’utente).

- void _Accel_Cali(float x_min, float x_max, float y_min, float y_max, float z_min, float

z_max), esegue il set dei bias utilizzati per la calibrazione.

RTC (RealTimeClock)

- typedef struct {
int16_t seconds;
int16_t minutes;
int16_t hour;
int16_t dayofweek;
int16_t dayofmonth;
int16_t month;
int16_t year;} DS3231Time, è l’oggetto utilizzato per ottenere I valori delle letture dall’RTC
- uint8_t decToBcd(int16_t val), Converti i normali numeri decimali in decimali codificati binary.
- int16_t bcdToDec(uint8_t val), Converti numeri decimali codificati binari in normali numeri decimali.
- void set_time (uint8_t sec, uint8_t min, uint8_t hour, uint8_t dow, uint8_t dom, uint8_t month, uint8_t year), esegue il set del time sull’RTC con i parametri passati, scrivendoli tramite protocollo I2C

all’indirizzo 0xD0 su 0x00

- void get_time (void), ottiene il tempo dall’RTC tramite una mem_read fatta all’indirizzo 0xD0 usato anche

nella funzione di set, e scrivendo i valori nella struttura DS3231Time.

- float get_temp (void), ottiene la temperatura dall’RTC tramite una mem_read fatta all’indirizzo 0xD0, 0x11

usato anche nella funzione di set, tornando il valore

- void force_temp_conv (void), tale funzione legge il valore dello status register e controlla se il bit BYS è

settato, tale bit serve a controllare se il dispositivo è impegnato nelle funzioni TCXO, dopo di che legge il valore

del registro di controllo e setta il valore di tale registro forzando a 1 il valore del bit CONV. Dunque, tale funzione

serve per forzare la conversione della temperatura.

Main

Il Main risulta pricipalmente un modulo di configurazione iniziale prima di far partire il kernel di freeRTOS, in particolare

chiama:

- int main(void), questa è la prima funzione chiamata all’avvio del programma, è importante per configurare tutto

ciò che è necessario prima di far partire il kernel di freeRTOS; in particolare chiama:

- HAL_Init(), per Configurare il prefetch della Flash, la cache per le istruzioni e la cache dei dati; per Impostare la

priorità delle interrupt; Usare systick come fonte di base dei tempi e configurare tick a 1ms; configurare l’hardware a

basso livello.

- SystemClock_Config(), in modo da Configurare la tensione di uscita del regolatore interno principale, poi

Inizializzare gli oscillatori RCC in base ai parametri specificati nella struttura RCC_OscInitTypeDef e inizializzare i

clock dei bus CPU, AHB e APB.

- MX_GPIO_Init(), inizializzare le porte di i/o (GPIO Ports Clock Enable, Configure GPIO pin Output

Level, Configure GPIO pin)

- MX_SPI1_Init(), per inizializzare la comunicazione tramite SPI (per il lettore della microSD)
- MX_USART2_UART_Init(), per inizializzare la comunicazione UART con il PC
- MX_FATFS_Init(), per inizializzare il file system in modo da poter usufruire della microSD
- | MX_I2C1_Init() | e MX_I2C3_Init(), per inizializzare la comunicazione tramite I2C utilizzata poi dai due

accelerometri e dal Real Time Clock.

- MPU6050_Init(&hi2c3), per inizializzare gli accelerometri i quali entrambi comunicheranno tramite l’handle di

I2C3

- myMpuConfig, per configurare gli accelerometri MPU 6050 (es. sensibilità, ecc..)
- MPU6050_Config(&myMpuConfig), per configurare gli accelerometri
- | Mount_SD("/"), Format_SD(), Create_File("ADT.TXT"), | Unmount_SD("/"), funzioni per aggiungere

il file ADT.txt che sarà utilizzato per il log

- osKernelInitialize(), per inizializzare il kernel

- MX_FREERTOS_Init(), per creare le due code e i quattro task che serviranno per il corretto funzionamento del

kernel

- osKernelStart(), per far partire il kernel dopo aver terminato le configurazioni
- void SystemClock_Config(void), Configura la tensione di uscita del regolatore interno principale, Inizializza gli

oscillatori RCC in base ai parametri specificati nella struttura RCC_OscInitTypeDef., Inizializza i clock dei bus

CPU, AHB e APB.

FreeRTOS

- void MX_FREERTOS_Init(void), all’interno di tale funzione vengono create le code LtoAqueueHandle e

AtoLogqueueHandle, la prima destinata alla comunicazione tra il task di lettura dei valori dai sensori e quello di

analisi di tali dati e la seconda destinata alla comunicazione tra il task di analisi e quello deputato alla scrittura dei

file di log. In fase di creazione di tali code, i valori passati alla funzione osMessageQueueNew sono quelli relativi

alla dimensione della coda, al tipo dei valori che conterrà e gli attributi definiti in fase di configurazione, tra cui il

nome. Si controlla la corretta creazione delle code che potrebbe essere ostacolata da spazio insufficiente nella

memoria heap. Si procede poi alla creazione dei task defaultTaskHandle, LectureTaskHandle, AnalysisTaskHandle,

LogTaskHandle. Alla funzione osThreadNew deputata alla creazione di tali task, si passano come argomenti le

funzioni associate ai task (rispettivamente StartDefaultTask, LectureFunction, AnalysisFunction, LogFunction), e

gli attributi di questi ultimi.

- void StartDefaultTask(void *argument), funzione associata al task di default, contenente le operazioni svolte

da quest’ultimo ogni qual volta risulta essere attivo (non è stata utilizzata nella nostra applicazione).

- void LectureFunction(void *argument), funzione associata al LectureTask. Tale funzione, ogni qual volta il

task è in esecuzione si occupa di prelevare i valori rilevati dagli accelerometri, inserirli all’interno della struttura

dati “Datastruct” il cui tipo è myData e di inviarli sulla coda LtoAqueue.

- void AnalysisFunction(void *argument), funzione associata all’AnalysisTask, controlla che la coda

LtoAqueue non sia vuota, e che quindi il task precedente gli abbia effettivamente mandato dei valori da analizzare.

Procede dunque all’analisi di tali valori, dopo averli adeguatamente scalati e ne individua la funzionalità

corrispondente che deve essere effettuata. Salva tali valori all’interno di una struttura “all_dataStruct” il cui tipo è

myData_2, contenente sia i valori degli accelerometri che la gesture ad essi associata, e procede all’invio di tale

struttura sulla coda AtoLogqueueHandle, trasmettendoli inoltre sulla huart, da cui saranno prelevati da pySerial.

- void LogFunction(void *argument), funzione associata al LogTask, controlla che la coda AtoLogqueueHandle

non sia vuota, e che quindi il task precedente gli abbia effettivamente mandato dei valori da trascrivere sul file di

Log. Rileva il timestamp dall’RTC e scrive tutte le informazioni necessarie sul file contenuto nell’SD Card. Ogni

volta si occupa di fare il “mount” e “l’unmount” dell’SD.

### Descrizione dei task e delle code create

Per la realizzazione del software si è previsto l’impiego di FreeRTOS. Come precedentemente descritto, sono stati creati tre

task diversi, a medesima priorità e con diverse funzionalità. I task implementati sono stati individuati a partire dalle funzionalità principali che dovevano essere offerte dal nostro sistema. Dunque, è stato realizzato un primo task LectureTask

deputato all’acquisizione dei dati dagli accelerometri, che ha una stack size di 128 word e la cui priorità è RealTime. Il

secondo task AnalysisTask deputato a riconoscere, a seconda dei valori ottenuti dagli accelerometri, quale sia il movimento

da compiere e inviare tale analisi alla uart in modo da comunicare poi con i moduli python, ha una stack size di 128 word e

una priorità RealTime. Il terzo task LogTask, invece, è deputato alla scrittura del file di log sulla scheda SD e ha una stack

size maggiore, pari a 2048 word, e una priorità RealTime. Dunque, il task di lettura è un task periodico. L’attività degli altri

due task è invece condizionata alla presenza di valori da analizzare all’interno delle code. Nello specifico le code create

sono state due: la prima LtoAqueue con una dimensione di 16 e predisposta a contenere valori del tipo myData, funge da

connessione tra il task di lettura e quello di analisi, la seconda AtoLogqueue con una dimensione di 16 e predisposta a

contenere valori del tipo my_Data2, funge da connessione tra il task di analisi e quello di log.

## 6 Interfaccia di comunicazione

## 6.1 Interfaccia UART

UART sta per Universal Asynchronous Receiver / Transmitter (ricevitore / trasmettitore asincrono universale) e definisce

un protocollo, o un insieme di regole, per lo scambio di dati seriali tra due dispositivi. Il protocollo UART è molto semplice

e utilizza solo due fili fra il trasmettitore e il ricevitore per trasmettere e ricevere in

entrambe le direzioni. Entrambe le estremità hanno anche una connessione a

massa. La comunicazione UART può essere simplex (i dati sono inviati in una

sola direzione), half-duplex (ogni lato parla ma solo uno alla volta) o full-

duplex (entrambi i lati possono trasmettere contemporaneamente). I dati in

un'interfaccia UART sono trasmessi sotto forma di frame. Il formato e il

contenuto di questi frame sono brevemente descritti e spiegati.

Uno dei grandi vantaggi del protocollo UART è che è asincrono: il trasmettitore e il ricevitore non condividono un segnale

di clock comune. Anche se questo semplifica molto il protocollo, pone alcuni requisiti al trasmettitore e al ricevitore.

Poiché non condividono un clock, entrambe le estremità devono trasmettere alla stessa velocità prestabilita per avere la

stessa tempistica dei bit. I baud rate UART più comuni in uso oggi sono 4800, 9600, 19,2K, 57,6K e 115,2K. Oltre ad

avere lo stesso baud rate, entrambi i lati di una connessione UART devono anche utilizzare la stessa struttura di frame e gli

stessi parametri. Per poter meglio comprendere di seguito si riporta la struttura di un frame UART.

### Formato dei frame

## 6.2 Interfaccia I2C

Il protocollo I2C (pronuncia I-quadro-C, in Inglese I-squared-C) è stato creato dalla Philips Semiconductors nel 1982; la

sigla, comunemente indicata anche con I2C, sta per Inter-

Integrated Circuit. Il protocollo permette la comunicazione di

dati tra due o più dispositivi I2C utilizzando un bus2 a due

fili, più uno per il riferimento comune di tensione, come si

vede nella figura riportata. Dunque, in tale protocollo le

informazioni sono inviate serialmente usando una linea per i dati (SDA: Serial Data line) ed una per il Clock (SCL: Serial

Clock line). Deve inoltre essere presente una terza linea: la massa, comune a tutti i dispositivi.

### Sequenza di trasferimento dati

Nello scambio di tali messaggi si configurano due tipologie di attori, master e slave. Una sequenza elementare di lettura o

scrittura di dati tra master e slave segue il seguente ordine, come riportato in figura:

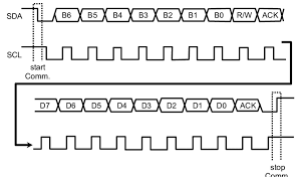
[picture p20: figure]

1. Invio del bit di START (S) da parte del master
2. Invio dell’indirizzo dello slave (ADDR)7 ad opera del master
3. Invio del bit di Read (R) o di Write (W), che valgono

rispettivamente 1 e 0 (sempre ad opera del master)

4. Attesa/invio del bit di Acknowledge (ACK)
5. Invio/ricezione del byte dei dati (DATA)
6. Attesa/invio del bit di Acknowledge (ACK)
7. Invio del bit di STOP (P) da parte del master

## 6.3 Interfaccia SPI

L’interfaccia SPI venne originariamente ideata dalla Motorola (ora Freescale) a supporto dei propri microprocessori e

microcontrollori. A differenza dello standard I2C ideato dalla Philips,

l’interfaccia SPI non è stata mai standardizzata; ciononostante è

divenuta di fatto uno standard. Il non avere delle regole ufficiali ha

portato all’aggiunta di molte caratteristiche ed opzioni che vanno

opportunamente selezionate ed impostate al fine di permettere una

corretta comunicazione tra le varie periferiche interconnesse.

L’interfaccia SPI descrive una comunicazione singolo Master - singolo Slave, ed è di tipo sincrono e full-duplex. Il clock

viene trasmesso con linea dedicata (non necessariamente una trasmissione sincrona ha una linea dedicata al clock) ed è

possibile sia trasmettere che ricevere dati in contemporanea. La figura sopra riportata rappresenta uno schema base di

collegamento tra due periferiche che fanno uso dell’interfaccia SPI.

Dalla Figura è possibile subito notare quanto appena detto, ovvero che la comunicazione avviene generalmente tra un

Master ed uno Slave. L’interfaccia presenta inoltre 4 linee di collegamento (esclusa la massa comunque necessaria), per cui

lo standard SPI è anche noto come 4 Wire Interface.
È compito del Master avviare la comunicazione e fornire il clock allo Slave. La nomenclatura delle varie linee presenti

nell’interfaccia SPI è normalmente la seguente:

MOSI : Master Output Slave Input

MISO : Master Input Slave Output

SCLK : Serial Clock (generato dal Master)

CS/SS : Chip Select, Slave Select, emesso dal master per scegliere con quale dispositivo slave vuole comunicare

### Sequenza di trasferimento dati

Vi sono due diverse modalità per il trasferimento dei dati:

CPHA=1:

CPOL=0:

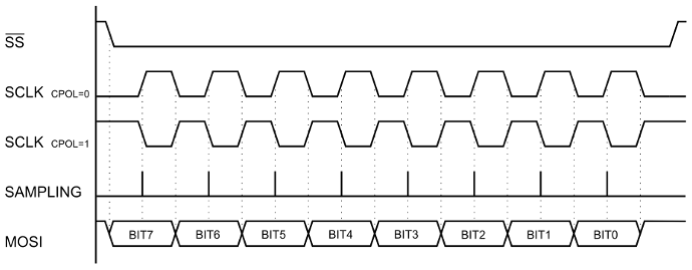
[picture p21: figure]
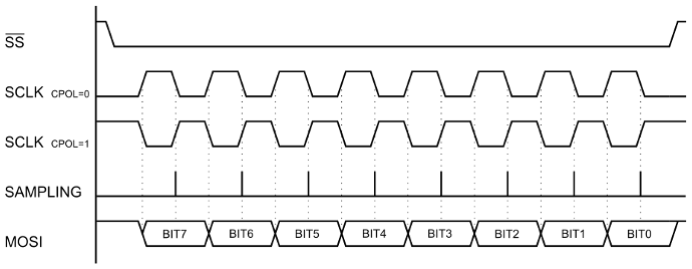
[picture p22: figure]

## 7 Software a supporto

Affinché si potessero tradurre le elaborazioni fatte sui dati bruti dell’accelerometro in gesture e movimenti del mouse, sono

state utilizzate alcune librerie esterne. Nello specifico il modulo pySerial è un modulo che incapsula l’accesso alla porta

seriale, mentre pyAutoGui consente, attraverso script python di realizzare un controllo semplice della tastiera e del mouse.

## 7.1 Librerie esterne

### PyAutoGui

PyAutoGUI è un modulo Python di automazione GUI

multipiattaforma per esseri umani, utilizzato per controllare a

livello di codice il mouse e la tastiera. Mette a disposizione diverse

funzionalità: movimento del mouse e realizzazione dei click anche

in finestre di altre applicazioni, invio di sequenze di tasti alle

diverse applicazioni, individuazione delle finestre delle applicazioni

con possibilità di spostarle, ridimensionarle, ingrandirle, ridurle a

icona o chiuderle. (Tali funzionalità attualmente sono integralmente supportate solo in windows). Consente inoltre la

visualizzazione di finestre di avviso e di messaggio.

### PySerial

Questo modulo incapsula l'accesso per la porta seriale. Fornisce backend

per Python (http://python.org/) in esecuzione su Windows, OSX, Linux, BSD (possibilmente qualsiasi

sistema conforme a POSIX) e IronPython. Il modulo denominato “seriale” seleziona

automaticamente il backend appropriato.

Tali due moduli di supporto sono stati necessari, in quanto, il modulo pySerial avendo accesso alla porta seriale ci ha

consentito di realizzare la comunicazione con la scheda STM32 in modo da poter acquisire i comandi di movimento

attraverso il protocollo di comunicazione UART. L’acquisizione di tali dati ne ha poi permesso l’elaborazione e la

traduzione in movimenti del mouse o in esecuzione di comandi quali il click, zoom-in, zoom-out, alt-tab, etc.., attraverso

l’impiego di PyAutoGui.

## Foto

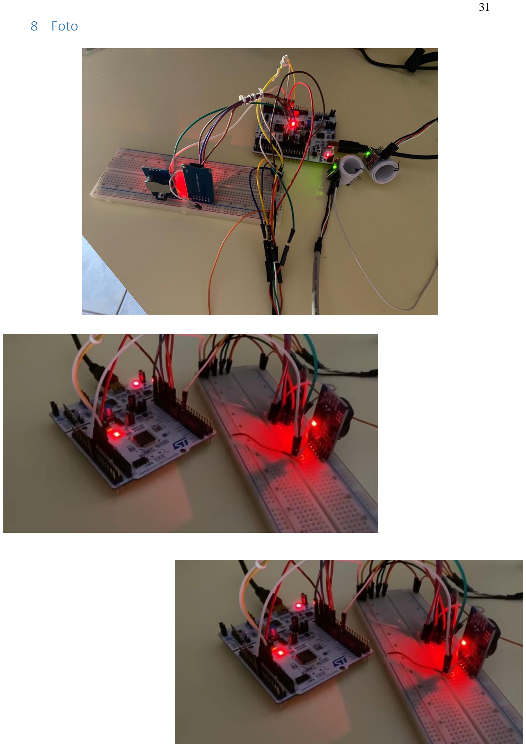
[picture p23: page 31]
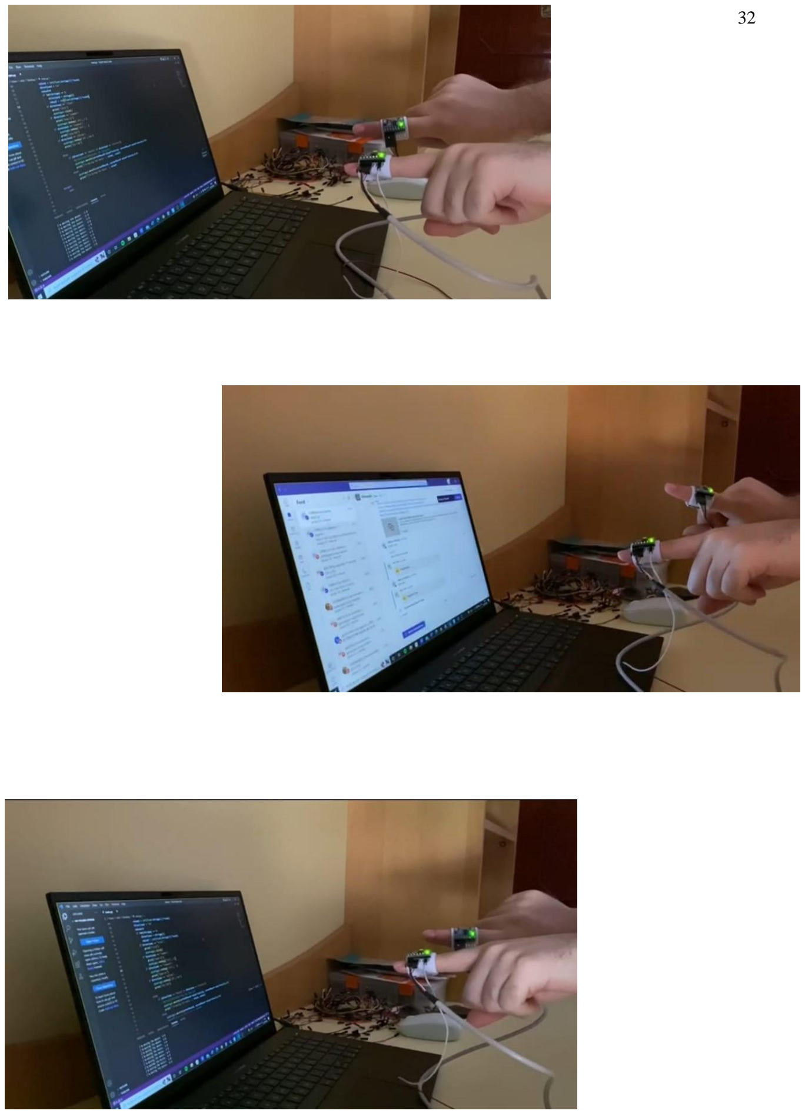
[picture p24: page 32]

## 9 Istruzioni di utilizzo

La configurazione realizzata prevede l’impiego di due accelerometri, ciascuno dei due posizionato sul dito indice della

mano. Sulla mano destra deve essere posizionato l’accelerometro il cui pin AD0 non è connesso all’alimentazione di 5Volt,

e sarà l’accelerometro deputato allo spostamento del mouse (movimenti verso destra, sinistra, sopra, sotto o eventuali

movimenti in obliquo), sulla mano sinistra invece dovrà essere fissato l’accelerometro con AD0 alimentato a 5Volt, che è

deputato ad effettuare le gesture (click, zoom-in, zoom-out, alt-tab).

Si riportano di seguito delle immagini esplicative per l’esecuzione dei comandi.

## 9.1 Mano Destra

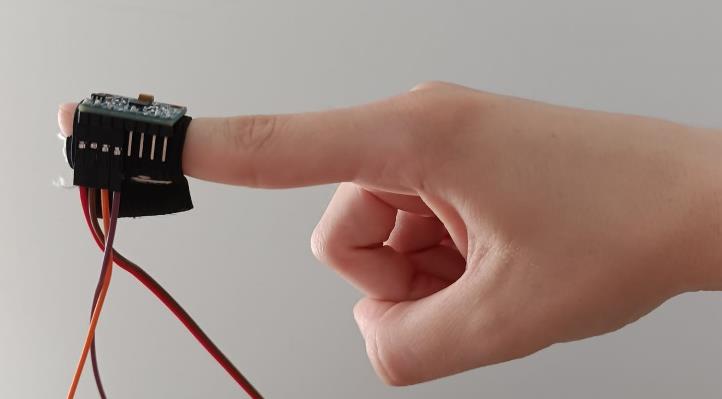
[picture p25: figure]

Nessun Movimento | Movimento verso destra

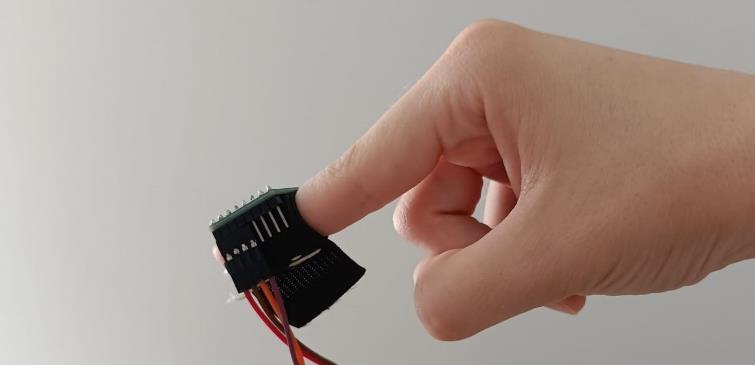
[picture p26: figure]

Movimento verso sinistra | Movimento verso il basso

Movimento verso l’alto

I movimenti obliqui (destra-sotto, destra-sopra, sinistra-sotto, sinistra-sopra) possono essere effettuati inclinando il dito appositamente rispetto alle orientazioni sopra illustrate.

## 9.2 Mano Sinistra

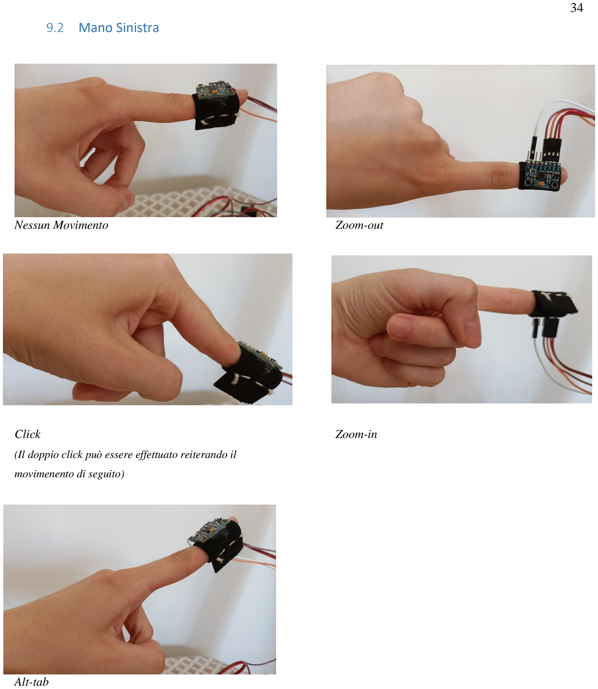
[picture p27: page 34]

Nessun Movimento | Zoom-out
Click | Zoom-in

(Il doppio click può essere effettuato reiterando il

movimenento di seguito)

Alt-tab

This work is licensed under the Creative Commons Attribution-NonCommercial-ShareAlike
4.0 International License. To view a copy of this license, visit http://creativecommons.org/licenses/by-nc-sa/4.0/ (http://creativecommons.org/licenses/by-nc-sa/4.0/) or send a letter to Creative Commons, PO Box 1866, Mountain View, CA 94042, USA.

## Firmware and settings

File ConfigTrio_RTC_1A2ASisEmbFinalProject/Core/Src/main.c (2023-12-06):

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
/* Includes ------------------------------------------------------------------*/
#include "main.h"
#include "i2c.h"
#include "usart.h"
#include "gpio.h"
#include <string.h>
#include <stdio.h>

/* USER CODE BEGIN Includes */
#include "TJ_MPU6050.h"
#include "ds3231.h"
/* USER CODE END Includes */


void SystemClock_Config(void);
/* USER CODE BEGIN 0 */
/*RTC struct*/
extern DS3231Time ds3231time;
/*AccelGyro struct*/
RawData_Def myAccelRaw,myGyroRaw;
ScaledData_Def myAccelScaled,myGyroScaled;
/* USER CODE END 0 */

/**
  * @brief  The application entry point.
  * @retval int
  */
int main(void)
{
  /* USER CODE BEGIN 1 */
	MPU_ConfigTypeDef myMpuConfig;
  /* USER CODE END 1 */

  /* MCU Configuration--------------------------------------------------------*/

  /* Reset of all peripherals, Initializes the Flash interface and the Systick. */
  HAL_Init();

  /* Configure the system clock */
  SystemClock_Config();

  /* Initialize all configured peripherals */
  MX_GPIO_Init();
  MX_USART2_UART_Init();
  MX_I2C1_Init();
  MX_I2C3_Init();
  /* USER CODE BEGIN 2 */
  MPU6050_Init(&hi2c1);
  myMpuConfig.Accel_Full_Scale = AFS_SEL_16g;
  myMpuConfig.ClockSource = Internal_8MHz;
  myMpuConfig.CONFIG_DLPF = DLPF_260A_256G_Hz;
  myMpuConfig.Gyro_Full_Scale = FS_SEL_250;
  myMpuConfig.Sleep_Mode_Bit = 0; //1:sleep mode, 0:normal mode
  MPU6050_Config(&myMpuConfig);
  char str[200];
  char buffer [100];
  _Accel_Cali(-17000,17000,-17000,17000,-17000,17000);
    /* Infinite loop */
    /* USER CODE BEGIN WHILE */
    while (1)
    {
    	/*1 AccelGyro */
    	MPU6050_Get_Accel_RawData(&myAccelRaw, 1);
        MPU6050_Get_Gyro_RawData(&myGyroRaw);
    	myAccelRaw.x= myAccelRaw.x*9.8*100/(2048);
    	myAccelRaw.y= myAccelRaw.y*9.8*100/(2048);
    	myAccelRaw.z= myAccelRaw.z*9.8*100/(2048);
  	    sprintf(str,"Primo ACCEL = Ax= %.2d , Ay= %.2d , Az= %.2d GYRO = Ax= %.2d , Ay= %.2d , Az= %.2d \n",myAccelRaw.x,myAccelRaw.y,myAccelRaw.z,myGyroRaw.x,myGyroRaw.y,myGyroRaw.z);
    	HAL_UART_Transmit(&huart2, (uint8_t *) str, strlen(str), HAL_MAX_DELAY);
  	  	HAL_UART_Transmit(&huart2, (uint8_t *) "\r", 1, HAL_MAX_DELAY);
  	  	HAL_Delay(1000);

  	  /*2 AccelGyro */
  	    MPU6050_Get_Accel_RawData(&myAccelRaw, 2);
  	    MPU6050_Get_Gyro_RawData(&myGyroRaw);
  	    myAccelRaw.x= myAccelRaw.x*9.8*100/(2048);
  	    myAccelRaw.y= myAccelRaw.y*9.8*100/(2048);
  	    myAccelRaw.z= myAccelRaw.z*9.8*100/(2048);
  	    sprintf(str,"Secondo ACCEL = Ax= %.2d , Ay= %.2d , Az= %.2d GYRO = Ax= %.2d , Ay= %.2d , Az= %.2d \n",myAccelRaw.x,myAccelRaw.y,myAccelRaw.z,myGyroRaw.x,myGyroRaw.y,myGyroRaw.z);
  	    HAL_UART_Transmit(&huart2, (uint8_t *) str, strlen(str), HAL_MAX_DELAY);
  	    HAL_UART_Transmit(&huart2, (uint8_t *) "\r", 1, HAL_MAX_DELAY);
  	    HAL_Delay(1000);


  	  	/* RTC */
  	  	get_time();
  	    sprintf (buffer, "%02d-%02d-20%02d %02d:%02d:%02d\n", ds3231time.dayofmonth, ds3231time.month, ds3231time.year, ds3231time.hour, ds3231time.minutes, ds3231time.seconds);
  	  	HAL_UART_Transmit(&huart2, (uint8_t *) buffer, strlen(buffer), HAL_MAX_DELAY);
  	  	HAL_UART_Transmit(&huart2, (uint8_t *) "\r", 1, HAL_MAX_DELAY);
  	  	HAL_Delay(1000);

    }
  /* USER CODE END 3 */
}

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


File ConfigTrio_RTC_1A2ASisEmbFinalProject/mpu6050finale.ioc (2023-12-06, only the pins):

Mcu.UserName=STM32F401RETx
PA13.GPIO_Label=TMS
PA13.Signal=SYS_JTMS-SWDIO
PA14.GPIO_Label=TCK
PA14.Signal=SYS_JTCK-SWCLK
PA2.GPIO_Label=USART_TX
PA2.Signal=USART2_TX
PA3.GPIO_Label=USART_RX
PA3.Signal=USART2_RX
PA5.GPIO_Label=LD2 [Green Led]
PA5.Signal=GPIO_Output
PA8.Signal=I2C3_SCL
PB3.GPIO_Label=SWO
PB3.Signal=SYS_JTDO-SWO
PB8.Signal=I2C1_SCL
PB9.Signal=I2C1_SDA
PC13-ANTI_TAMP.GPIO_Label=B1 [Blue PushButton]
PC13-ANTI_TAMP.Signal=GPXTI13
PC9.Signal=I2C3_SDA

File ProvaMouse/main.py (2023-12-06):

# This is a sample Python script.
import pyautogui
import serial


import time
# Press Maiusc+F10 to execute it or replace it with your code.
# Press Double Shift to search everywhere for classes, files, tool windows, actions, and settings.


def print_hi(name):
    # Use a breakpoint in the code line below to debug your script.
    print(f'Hi, {name}')  # Press Ctrl+F8 to toggle the breakpoint.
    screenWidth ,  screenHeight  =  pyautogui.size ()  # Restituisce due numeri interi, la larghezza e l'altezza dello schermo. (Il monitor principale, nelle configurazioni multi-monitor.)
    currentMouseX ,  currentMouseY  =  pyautogui.position ()
    pyautogui.moveTo(40, 190)
    pyautogui.click () # Fare clic con il mouse nella posizione corrente.
    pyautogui.click (200 ,  220)  # Fare clic con il mouse sulle coordinate x, y 200, 220.
    #pyautogui.move (None, 100)# Sposta il mouse di 10 pixel verso il basso, ovvero sposta il mouse rispetto alla sua posizione corrente.


    print(currentMouseX,currentMouseY)

def translate(value, leftMin, leftMax, rightMin, rightMax):
    # Figure out how 'wide' each range is
    leftSpan = leftMax - leftMin
    rightSpan = rightMax - rightMin

    # Convert the left range into a 0-1 range (float)
    valueScaled = float(value - leftMin) / float(leftSpan)

    # Convert the 0-1 range into a value in the right range.return rightMin + (valueScaled * rightSpan)



# Press the green button in the gutter to run the script.
if __name__ == '__main__':
    ser = serial.Serial('COM3')
    print("camilla ti puoi muovere!!")
    while(1):
        velocity = 7
        x = ser.readline()
        try:
            stringa = str(x).split('\\')[1][1:].split(" ")
            currentMouseX ,  currentMouseY  =  pyautogui.position ()
            if len(stringa) > 1:
                direction1 = stringa[0]
                value1 = int(float(stringa[1]))
                direction2 = "no"
                value2=0
                if len(stringa) == 5:
                    direction2 = stringa[2]
                    value2 = int(float(stringa[3]))
                if direction1 == "click":
                    print("click")
                    pyautogui.click()
                else:
                    if (direction1 == "destra" or direction1 == "sinistra"):
                        #print(translate(value,-10,-10,1,10))
                        pyautogui.moveTo(currentMouseX-value1*velocity, currentMouseY-value2*velocity,0.01)
                        print("sto andando denstra sinistra forse obliguo: ", value1, value2)
                    else:
                        pyautogui.moveTo(currentMouseX, currentMouseY-value1*velocity,0.01)
                        print("sto andando sotto o sopra ")
        except:
            pass



# See PyCharm help at https://www.jetbrains.com/help/pycharm/

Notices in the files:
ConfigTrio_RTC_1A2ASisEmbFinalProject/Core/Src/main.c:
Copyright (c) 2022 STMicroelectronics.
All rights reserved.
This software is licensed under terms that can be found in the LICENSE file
